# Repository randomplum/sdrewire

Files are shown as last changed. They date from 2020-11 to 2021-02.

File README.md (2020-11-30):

# SDReWire

Modern SD card muxer - allows to mux a SD card between an on-board USB SD card
reader and the device SDReWire is plugged into. This is useful for developing
and testing (embedded) systems which often require SD cards to boot from. It
allows to access the SD card on the target system as well as from the host
system connected via USB without having to touch the SD card.
 
Inspiried by the SDWire.

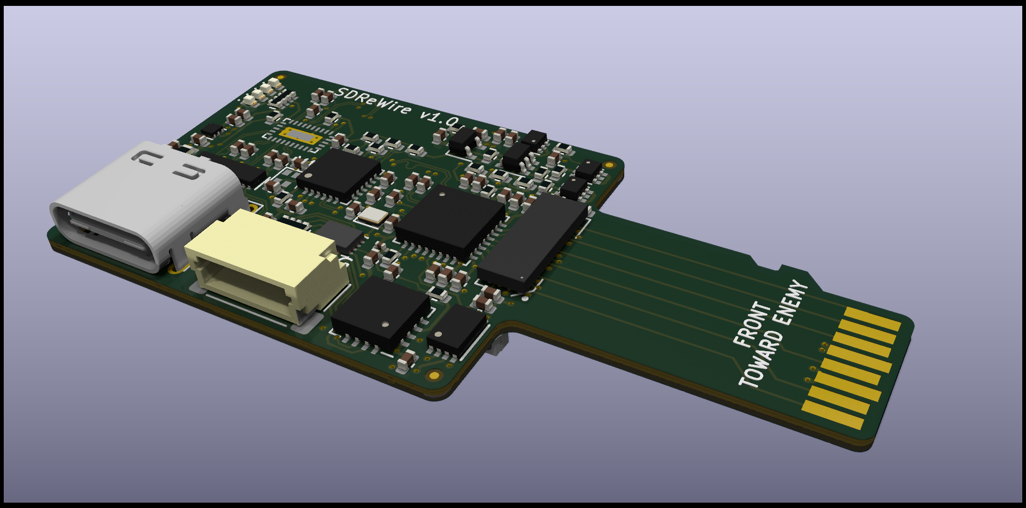
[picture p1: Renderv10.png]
Render


## Features

- USB-C connector for host system
- High speed signal muxer to mux SD signals
- SDXC/UHS capable design
- USB 3.1 Gen1 card reader (90MB/s+)
- FTDI for SD muxing and auxiliary port
- Auxiliary port featuring:
  - UART
  - 2 GPIO (1x output only)
  - 1.2V/1.8V/3.3V capable

Currenlty SDReWire is still in testing and development phase.

### Details

In case you wonder what exact components are used, here is the gist:

- USB 3.1 Gen1 card reader Genesys Logic GL3224
- TS3DDR4000ZBAR mux IC used for SD signals
- FTDI FT230XQ provides GPIO for mux as well as auxiliary UART and GPIO
- USB2422 USB 2.0 Hub to interface GL3224 and FTDI FT230XQ
  
Designed with KiCad.

## License

Licensed under the CERN-OHL-W (CERN Open Hardware Licence Version 2 - Weakly
Reciprocal, see LICENSE).

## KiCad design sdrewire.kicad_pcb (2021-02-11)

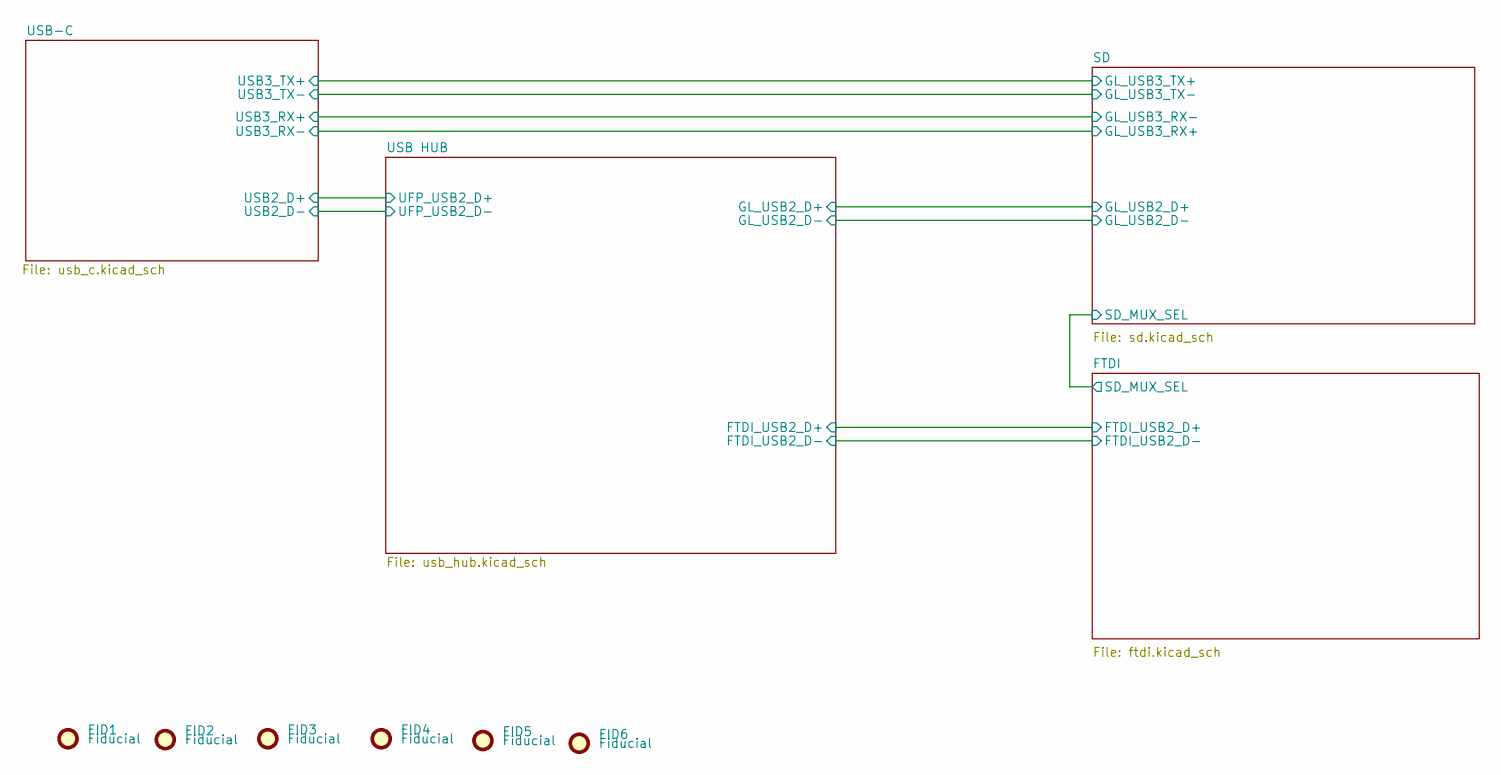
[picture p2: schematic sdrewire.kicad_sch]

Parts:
FID1, FID2, FID3, FID4, FID5, FID6: Fiducial; Fiducial_0.5mm_Mask1mm

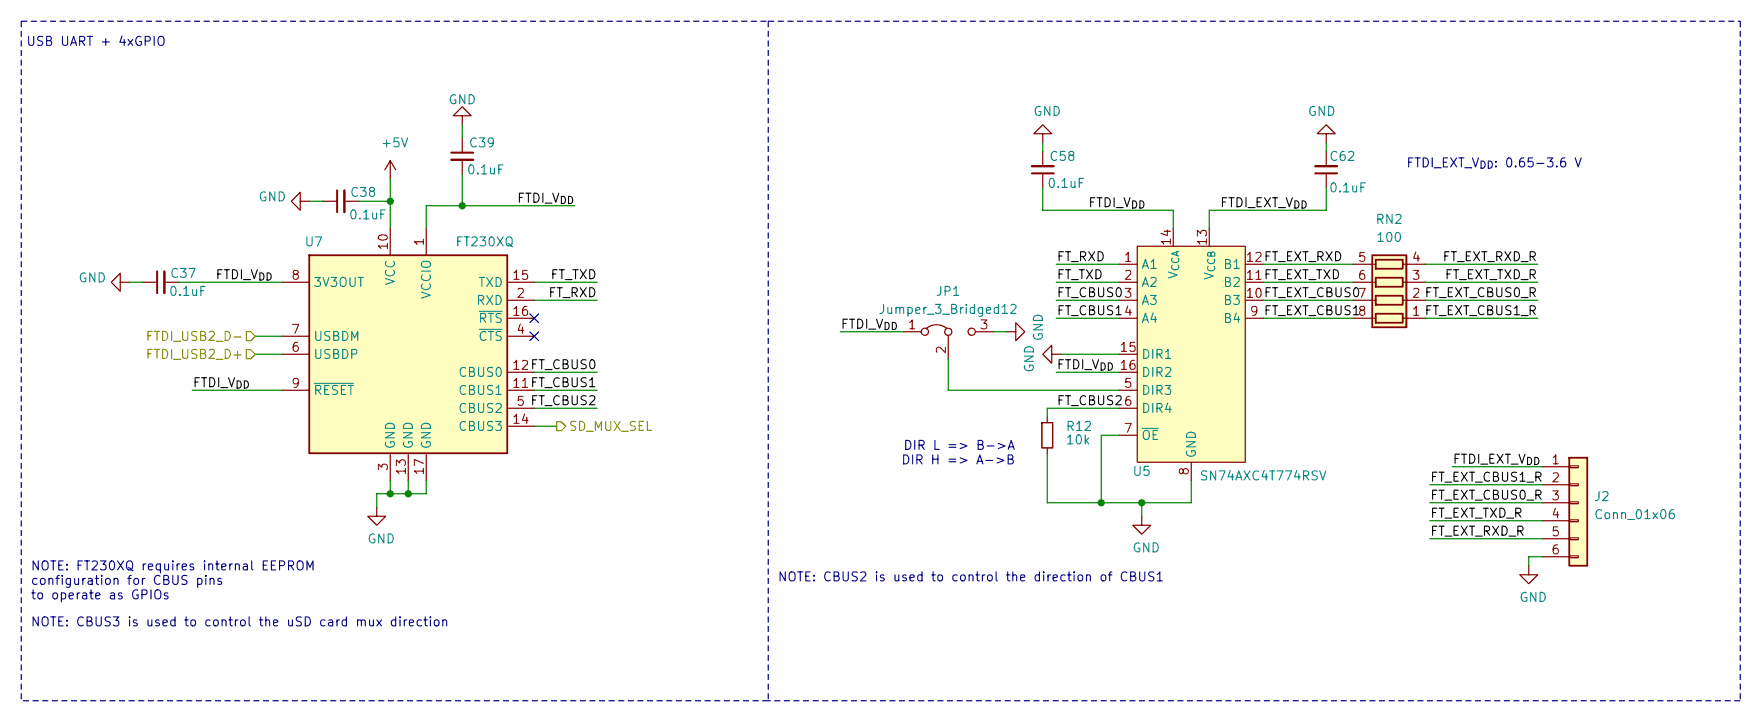
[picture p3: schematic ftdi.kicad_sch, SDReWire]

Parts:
C37, C38, C39, C58, C62: 0.1uF; C_0402_1005Metric
J2: Conn_01x06; JST_SH_SM06B-SRSS-TB_1x06-1MP_P1.00mm_Horizontal
JP1: Jumper_3_Bridged12; SolderJumper-3_P1.3mm_Bridged12_RoundedPad1.0x1.5mm_NumberL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
R12: 10k; R_0402_1005Metric
RN2: 100; R_Array_Convex_4x0402
U5: SN74AXC4T774RSV; QFN-16_1.8x2.6_Pitch0.4mm
U7: FT230XQ; QFN-16-1EP_4x4mm_P0.65mm_EP2.1x2.1mm

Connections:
+5V: C38.2, U7.10 (VCC); also elsewhere on the board
/FTDI/FTDI_EXT_V_{DD}: C62.1, J2.1, U5.13 (V_{CCB})
/FTDI/FTDI_USB2_D+: U7.6 (USBDP); also elsewhere on the board
/FTDI/FTDI_USB2_D-: U7.7 (USBDM); also elsewhere on the board
/FTDI/FTDI_V_{DD}: C37.2, C39.2, C58.1, JP1.1 (A), U5.14 (V_{CCA}), U5.16 (DIR2), U7.1 (VCCIO), U7.8 (3V3OUT), U7.9 (~RESET)
/FTDI/FT_CBUS0: U5.3 (A3), U7.12 (CBUS0)
/FTDI/FT_CBUS1: U5.4 (A4), U7.11 (CBUS1)
/FTDI/FT_CBUS2: R12.1, U5.6 (DIR4), U7.5 (CBUS2)
/FTDI/FT_EXT_CBUS0: RN2.7 (R2.2), U5.10 (B3)
/FTDI/FT_EXT_CBUS0_R: J2.3, RN2.2 (R2.1)
/FTDI/FT_EXT_CBUS1: RN2.8 (R1.2), U5.9 (B4)
/FTDI/FT_EXT_CBUS1_R: J2.2, RN2.1 (R1.1)
/FTDI/FT_EXT_RXD: RN2.5 (R4.2), U5.12 (B1)
/FTDI/FT_EXT_RXD_R: J2.5, RN2.4 (R4.1)
/FTDI/FT_EXT_TXD: RN2.6 (R3.2), U5.11 (B2)
/FTDI/FT_EXT_TXD_R: J2.4, RN2.3 (R3.1)
/FTDI/FT_RXD: U5.1 (A1), U7.2 (RXD)
/FTDI/FT_TXD: U5.2 (A2), U7.15 (TXD)
/FTDI/SD_MUX_SEL: U7.14 (CBUS3); also elsewhere on the board
GND: C37.1, C38.1, C39.1, C58.2, C62.2, J2.6, JP1.3 (B), R12.2, U5.7 (~OE), U5.8 (GND), U5.15 (DIR1), U7.3 (GND), U7.13 (GND), U7.17 (GND); also elsewhere on the board
unnamed: JP1.2 (C), U5.5 (DIR3)

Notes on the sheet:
USB UART + 4xGPIO
NOTE: FT230XQ requires internal EEPROM configuration for CBUS pins to operate as GPIOs
NOTE: CBUS3 is used to control the uSD card mux direction
NOTE: CBUS2 is used to control the direction of CBUS1
DIR L => B->A DIR H => A->B
FTDI_EXT_V_{DD}: 0.65-3.6 V

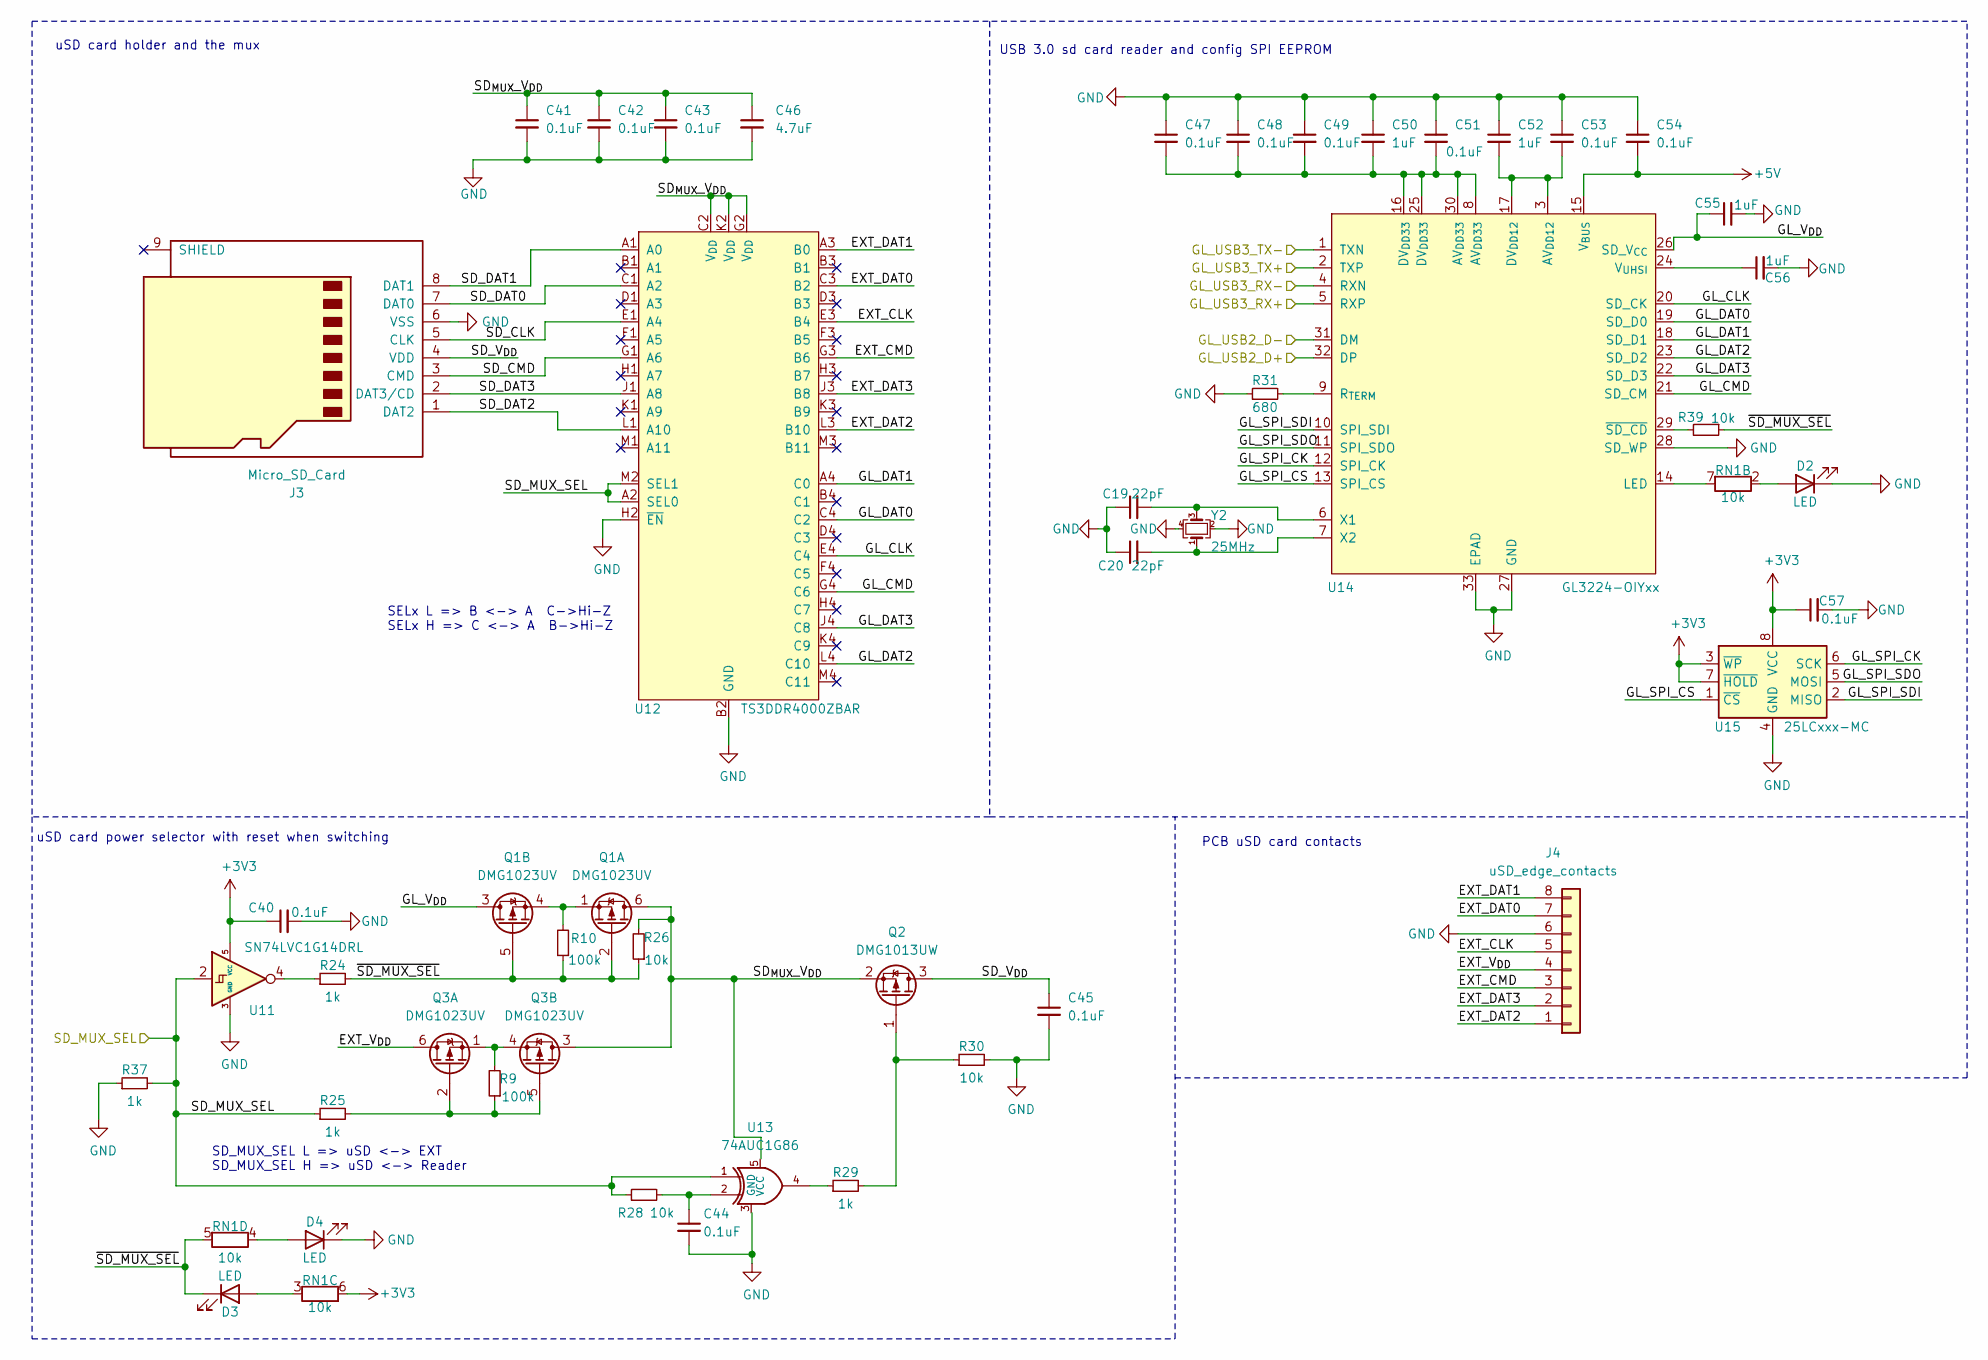
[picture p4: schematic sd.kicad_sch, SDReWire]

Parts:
C19, C20: 22pF; C_0402_1005Metric
C40, C41, C42, C43, C44, C45, C47, C48, C49, C51, C53, C54, C57: 0.1uF; C_0402_1005Metric
C46: 4.7uF; C_0402_1005Metric
C50, C52, C55, C56: 1uF; C_0402_1005Metric
D2, D3, D4: LED; LED_0402_1005Metric
J3: Micro_SD_Card; microSD_HC_Wuerth_693072010801
J4: uSD_edge_contacts; uSD_PCB
Q1, Q3: DMG1023UV; SOT-563
Q2: DMG1013UW; SOT-323_SC-70
R9, R10: 100k; R_0402_1005Metric
R24, R25, R29, R37: 1k; R_0402_1005Metric
R26, R28, R30, R39: 10k; R_0402_1005Metric
R31: 680; R_0402_1005Metric
RN1: 10k; R_Array_Convex_4x0402
U11: SN74LVC1G14DRL; SOT-553
U12: TS3DDR4000ZBAR; Texas_NFBGA-48_3.1x8.1mm_Layout4x12_P0.65mm
U13: 74AUC1G86; SOT-353_SC-70-5
U14: GL3224-OIYxx; QFN-32-1EP_5x5mm_P0.5mm_EP3.1x3.1mm
U15: 25LCxxx-MC; DFN-8-1EP_3x2mm_P0.5mm_EP1.75x1.45mm
Y2: 25MHz; Oscillator_SMD_Abracon_ASCO-4Pin_1.6x1.2mm

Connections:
+3V3: C40.1, C57.1, RN1.6 (R3.2), U11.5 (VCC), U15.3 (~WP), U15.7 (~HOLD), U15.8 (VCC); also elsewhere on the board
+5V: C54.2, U14.15 (V_{BUS}); also elsewhere on the board
/FTDI/SD_MUX_SEL: R25.1, R28.1, R37.2, U11.2, U12.A2 (SEL0), U12.M2 (SEL1), U13.1; also elsewhere on the board
/SD/EXT_CLK: J4.5, U12.E3 (B4)
/SD/EXT_CMD: J4.3, U12.G3 (B6)
/SD/EXT_DAT0: J4.7, U12.C3 (B2)
/SD/EXT_DAT1: J4.8, U12.A3 (B0)
/SD/EXT_DAT2: J4.1, U12.L3 (B10)
/SD/EXT_DAT3: J4.2, U12.J3 (B8)
/SD/EXT_V_{DD}: J4.4, Q3.6 (D)
/SD/GL_CLK: U12.E4 (C4), U14.20 (SD_CK)
/SD/GL_CMD: U12.G4 (C6), U14.21 (SD_CM)
/SD/GL_DAT0: U12.C4 (C2), U14.19 (SD_D0)
/SD/GL_DAT1: U12.A4 (C0), U14.18 (SD_D1)
/SD/GL_DAT2: U12.L4 (C10), U14.23 (SD_D2)
/SD/GL_DAT3: U12.J4 (C8), U14.22 (SD_D3)
/SD/GL_SPI_CK: U14.12 (SPI_CK), U15.6 (SCK)
/SD/GL_SPI_CS: U14.13 (SPI_CS), U15.1 (~CS)
/SD/GL_SPI_SDI: U14.10 (SPI_SDI), U15.2 (MISO)
/SD/GL_SPI_SDO: U14.11 (SPI_SDO), U15.5 (MOSI)
/SD/GL_USB2_D+: U14.32 (DP); also elsewhere on the board
/SD/GL_USB2_D-: U14.31 (DM); also elsewhere on the board
/SD/GL_USB3_RX+: U14.5 (RXP); also elsewhere on the board
/SD/GL_USB3_RX-: U14.4 (RXN); also elsewhere on the board
/SD/GL_USB3_TX+: U14.2 (TXP); also elsewhere on the board
/SD/GL_USB3_TX-: U14.1 (TXN); also elsewhere on the board
/SD/GL_V_{DD}: C55.1, Q1.3 (D), U14.26 (SD_V_{CC})
/SD/SD_CLK: J3.5 (CLK), U12.E1 (A4)
/SD/SD_CMD: J3.3 (CMD), U12.G1 (A6)
/SD/SD_DAT0: J3.7 (DAT0), U12.C1 (A2)
/SD/SD_DAT1: J3.8 (DAT1), U12.A1 (A0)
/SD/SD_DAT2: J3.1 (DAT2), U12.L1 (A10)
/SD/SD_DAT3: J3.2 (DAT3/CD), U12.J1 (A8)
/SD/SD_V_{DD}: C45.1, J3.4 (VDD), Q2.3 (D)
/SD/SD_{MUX}_V_{DD}: C41.1, C42.1, C43.1, C46.1, Q1.6 (D), Q2.2 (S), Q3.3 (D), R26.2, U12.C2 (V_{DD}), U12.G2 (V_{DD}), U12.K2 (V_{DD})
/SD/~SD_MUX_SEL: D3.1 (K), Q1.2 (G), Q1.5 (G), R10.1, R24.2, R26.1, R39.1, RN1.5 (R4.2)
GND: C19.1, C20.1, C40.2, C41.2, C42.2, C43.2, C44.2, C45.2, C46.2, C47.1, C48.1, C49.1, C50.1, C51.1, C52.1, C53.1, C54.1, C55.2, C56.2, C57.2, D2.1 (K), D4.1 (K), J3.6 (VSS), J4.6, R30.2, R31.1, R37.1, U11.3 (GND), U12.B2 (GND), U12.D2 (GND), U12.E2 (GND), U12.F2 (GND), U12.H2 (~EN), U12.J2 (GND), U12.L2 (GND), U14.27 (GND), U14.28 (SD_WP), U14.33 (EPAD), U15.4 (GND), U15.9 (GND), Y2.2, Y2.4; also elsewhere on the board
unnamed: C19.2, U14.6 (X1), Y2.3
unnamed: C20.2, U14.7 (X2), Y2.1
unnamed: C44.1, R28.2, U13.2
unnamed: C47.2, C48.2, C49.2, C50.2, C51.2, U14.8 (AV_{DD33}), U14.16 (DV_{DD33}), U14.25 (DV_{DD33}), U14.30 (AV_{DD33})
unnamed: C52.2, C53.2, U14.3 (AV_{DD12}), U14.17 (DV_{DD12})
unnamed: C56.1, U14.24 (V_{UHSI})
unnamed: D2.2 (A), RN1.2 (R2.1)
unnamed: D3.2 (A), RN1.3 (R3.1)
unnamed: D4.2 (A), RN1.4 (R4.1)
unnamed: Q1.1 (S), Q1.4 (S), R10.2
unnamed: Q2.1 (G), R29.2, R30.1
unnamed: Q3.1 (S), Q3.4 (S), R9.2
unnamed: Q3.2 (G), Q3.5 (G), R9.1, R25.2
unnamed: R24.1, U11.4
unnamed: R29.1, U13.4
unnamed: R31.2, U14.9 (R_{TERM})
unnamed: R39.2, U14.29 (~SD_CD)
unnamed: RN1.7 (R2.2), U14.14 (LED)

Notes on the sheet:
uSD card power selector with reset when switching
SD_MUX_SEL L => uSD <-> EXT SD_MUX_SEL H => uSD <-> Reader
uSD card holder and the mux
SELx L => B <-> A C->Hi-Z SELx H => C <-> A B->Hi-Z
USB 3.0 sd card reader and config SPI EEPROM
PCB uSD card contacts

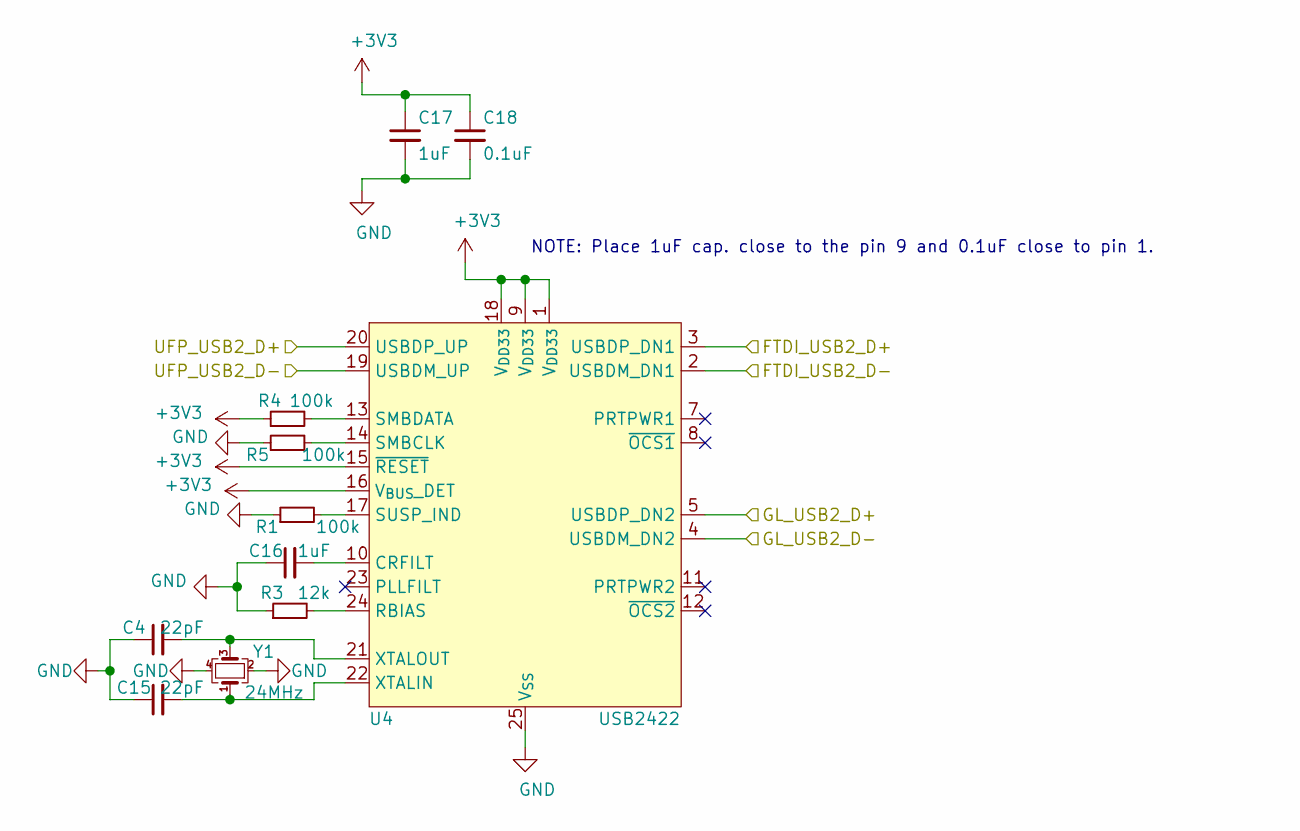
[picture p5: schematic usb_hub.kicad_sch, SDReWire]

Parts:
C4, C15: 22pF; C_0402_1005Metric
C16, C17: 1uF; C_0402_1005Metric
C18: 0.1uF; C_0402_1005Metric
R1, R4, R5: 100k; R_0402_1005Metric
R3: 12k; R_0402_1005Metric
U4: USB2422; QFN-24-1EP_4x4mm_P0.5mm_EP2.6x2.6mm
Y1: 24MHz; Oscillator_SMD_Abracon_ASCO-4Pin_1.6x1.2mm

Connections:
+3V3: C17.1, C18.1, R4.1, U4.1 (V_{DD33}), U4.9 (V_{DD33}), U4.15 (~RESET), U4.16 (V_{BUS}_DET), U4.18 (V_{DD33}); also elsewhere on the board
/FTDI/FTDI_USB2_D+: U4.3 (USBDP_DN1); also elsewhere on the board
/FTDI/FTDI_USB2_D-: U4.2 (USBDM_DN1); also elsewhere on the board
/SD/GL_USB2_D+: U4.5 (USBDP_DN2); also elsewhere on the board
/SD/GL_USB2_D-: U4.4 (USBDM_DN2); also elsewhere on the board
/USB HUB/UFP_USB2_D+: U4.20 (USBDP_UP); also elsewhere on the board
/USB HUB/UFP_USB2_D-: U4.19 (USBDM_UP); also elsewhere on the board
GND: C4.1, C15.1, C16.1, C17.2, C18.2, R1.1, R3.1, R5.1, U4.25 (V_{SS}), Y1.2, Y1.4; also elsewhere on the board
unnamed: C4.2, U4.21 (XTALOUT), Y1.3
unnamed: C15.2, U4.22 (XTALIN), Y1.1
unnamed: C16.2, U4.10 (CRFILT)
unnamed: R3.2, U4.24 (RBIAS)
unnamed: R4.2, U4.13 (SMBDATA)
unnamed: R5.2, U4.14 (SMBCLK)
unnamed: R1.2, U4.17 (SUSP_IND)

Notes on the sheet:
NOTE: Place 1uF cap. close to the pin 9 and 0.1uF close to pin 1.

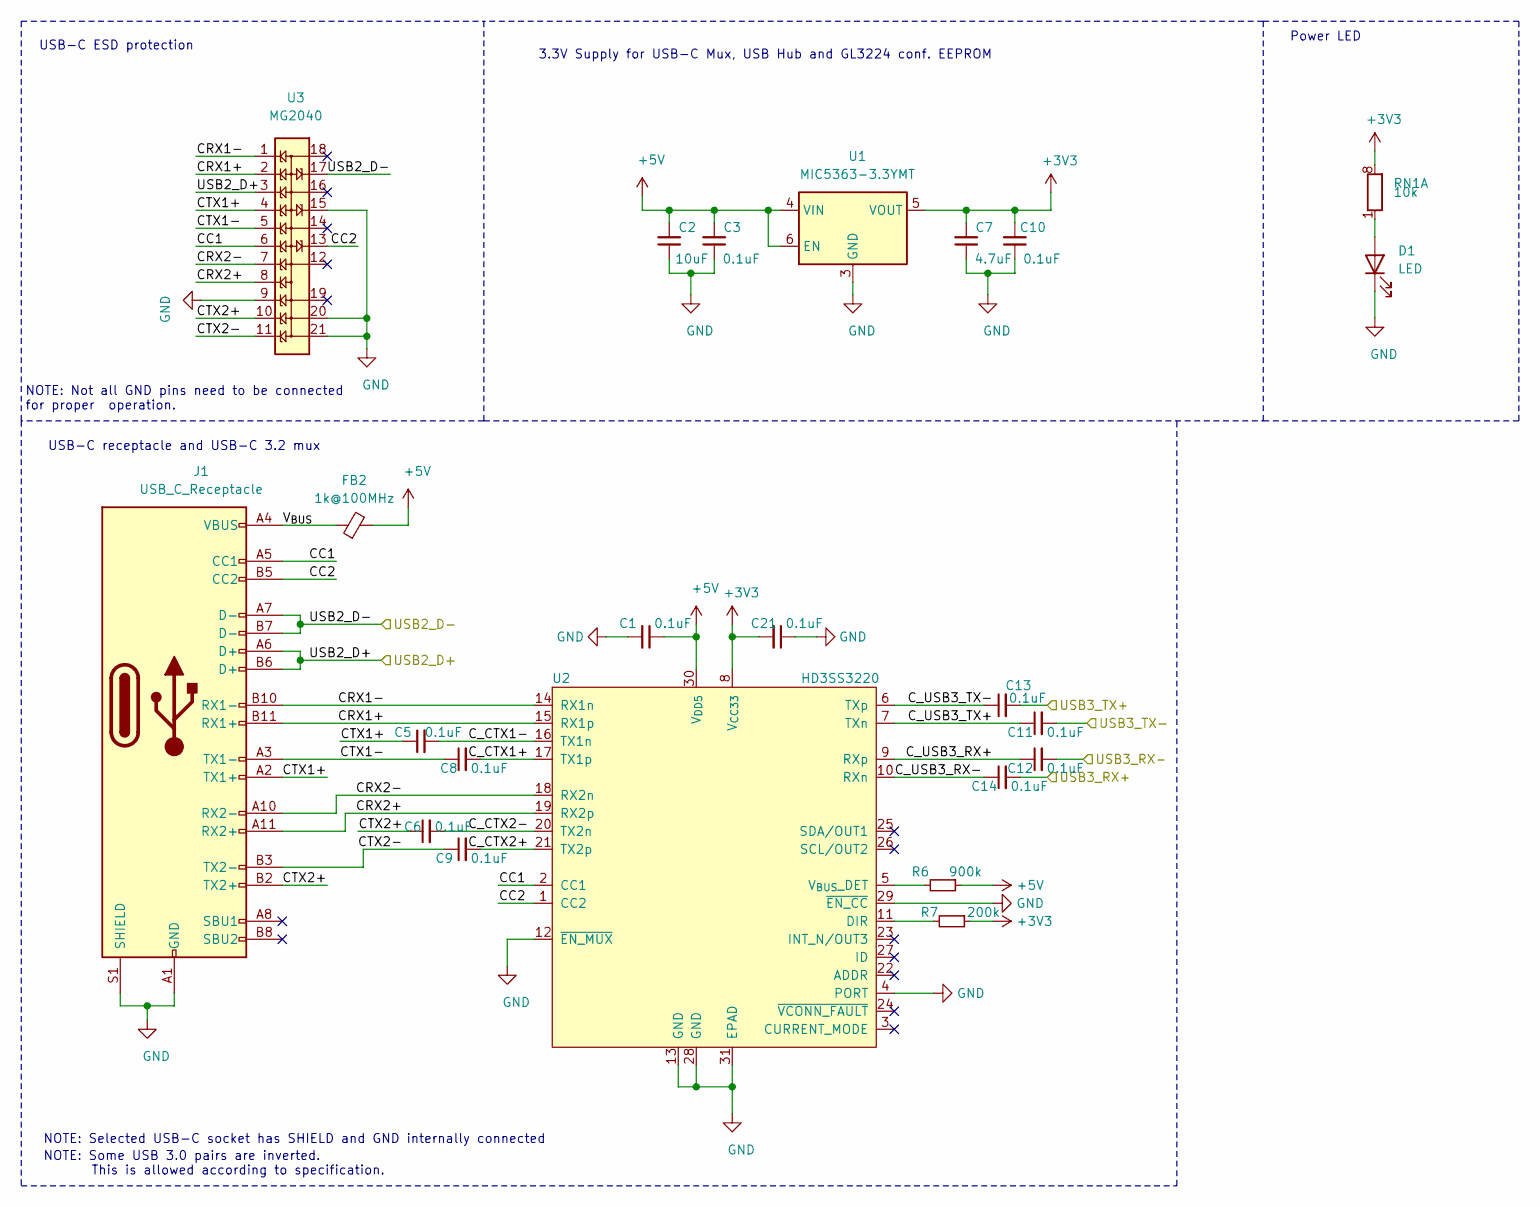
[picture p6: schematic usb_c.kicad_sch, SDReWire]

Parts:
C1, C3, C5, C6, C8, C9, C10, C11, C12, C13, C14, C21: 0.1uF; C_0402_1005Metric
C2: 10uF; C_0402_1005Metric
C7: 4.7uF; C_0402_1005Metric
D1: LED; LED_0402_1005Metric
FB2: 1k@100MHz; R_0603_1608Metric
J1: USB_C_Receptacle; USB_C_Receptacle_Molex_1054500101
R6: 900k; R_0402_1005Metric
R7: 200k; R_0402_1005Metric
RN1: 10k; R_Array_Convex_4x0402
U1: MIC5363-3.3YMT; DFN-6-1EP_1.2x1.2mm_P0.4mm_EP0.3x0.94mm_PullBack
U2: HD3SS3220; WQFP-30-1EP_4.6x2.6mm_P0.4mm_EP3.2x1.2mm
U3: MG2040; UDFN-18-3EP_5.5x1.5mm_P0.5mm_EP0.5x0.5mm

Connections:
+3V3: C7.2, C10.2, C21.2, R7.1, RN1.8 (R1.2), U1.5 (VOUT), U2.8 (V_{CC33}); also elsewhere on the board
+5V: C1.1, C2.2, C3.2, FB2.2, R6.1, U1.4 (VIN), U1.6 (EN), U2.30 (V_{DD5}); also elsewhere on the board
/SD/GL_USB3_RX+: C12.2; also elsewhere on the board
/SD/GL_USB3_RX-: C14.2; also elsewhere on the board
/SD/GL_USB3_TX+: C13.2; also elsewhere on the board
/SD/GL_USB3_TX-: C11.2; also elsewhere on the board
/USB HUB/UFP_USB2_D+: J1.A6 (D+), J1.B6 (D+), U3.3; also elsewhere on the board
/USB HUB/UFP_USB2_D-: J1.A7 (D-), J1.B7 (D-), U3.17; also elsewhere on the board
/USB-C/CC1: J1.A5 (CC1), U2.2 (CC1), U3.6
/USB-C/CC2: J1.B5 (CC2), U2.1 (CC2), U3.13
/USB-C/CRX1+: J1.B11 (RX1+), U2.15 (RX1p), U3.2
/USB-C/CRX1-: J1.B10 (RX1-), U2.14 (RX1n), U3.1
/USB-C/CRX2+: J1.A11 (RX2+), U2.19 (RX2p), U3.8
/USB-C/CRX2-: J1.A10 (RX2-), U2.18 (RX2n), U3.7
/USB-C/CTX1+: C5.1, J1.A2 (TX1+), U3.4
/USB-C/CTX1-: C8.1, J1.A3 (TX1-), U3.5
/USB-C/CTX2+: C6.1, J1.B2 (TX2+), U3.10
/USB-C/CTX2-: C9.1, J1.B3 (TX2-), U3.11
/USB-C/C_CTX1+: C8.2, U2.17 (TX1p)
/USB-C/C_CTX1-: C5.2, U2.16 (TX1n)
/USB-C/C_CTX2+: C9.2, U2.21 (TX2p)
/USB-C/C_CTX2-: C6.2, U2.20 (TX2n)
/USB-C/C_USB3_RX+: C12.1, U2.9 (RXp)
/USB-C/C_USB3_RX-: C14.1, U2.10 (RXn)
/USB-C/C_USB3_TX+: C11.1, U2.7 (TXn)
/USB-C/C_USB3_TX-: C13.1, U2.6 (TXp)
/USB-C/V_{BUS}: FB2.1, J1.A4 (VBUS), J1.A9 (VBUS), J1.B4 (VBUS), J1.B9 (VBUS)
GND: C1.2, C2.1, C3.1, C7.1, C10.1, C21.1, D1.1 (K), J1.A1 (GND), J1.A12 (GND), J1.B1 (GND), J1.B12 (GND), J1.S1 (SHIELD), U1.3 (GND), U1.7 (ePad), U2.4 (PORT), U2.12 (~EN_MUX), U2.13 (GND), U2.28 (GND), U2.29 (~EN_CC), U2.31 (EPAD), U3.9, U3.15, U3.20, U3.21; also elsewhere on the board
unnamed: D1.2 (A), RN1.1 (R1.1)
unnamed: R6.2, U2.5 (V_{BUS}_DET)
unnamed: R7.2, U2.11 (DIR)

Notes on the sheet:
NOTE: Not all GND pins need to be connected for proper operation.
USB-C ESD protection
NOTE: Selected USB-C socket has SHIELD and GND internally connected
NOTE: Some USB 3.0 pairs are inverted. This is allowed according to specification.
USB-C receptacle and USB-C 3.2 mux
3.3V Supply for USB-C Mux, USB Hub and GL3224 conf. EEPROM
Power LED

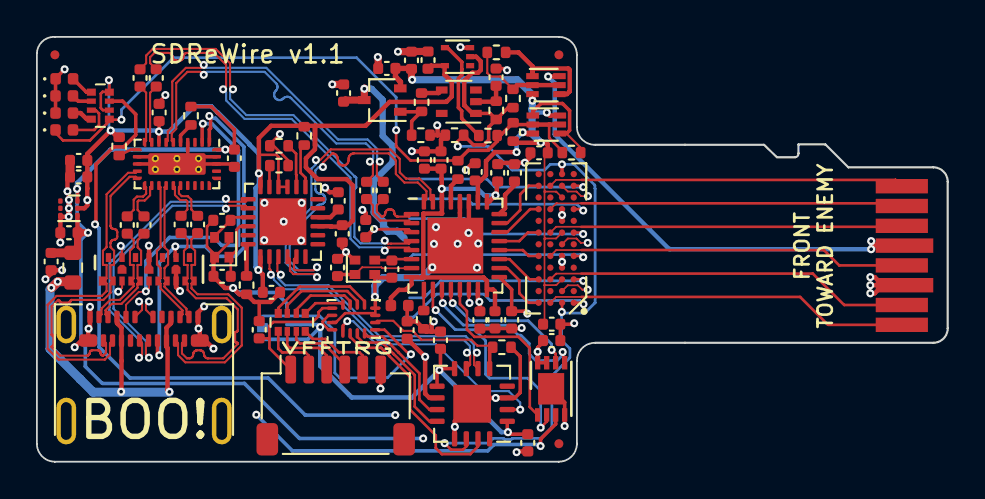
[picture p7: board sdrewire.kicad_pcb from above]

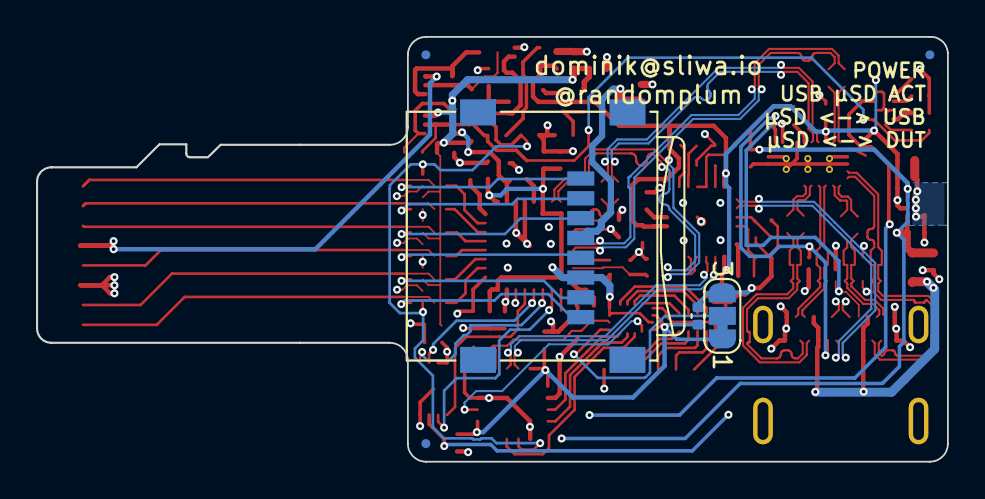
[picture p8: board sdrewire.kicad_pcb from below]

Board: 4 copper layers, 50.6 x 23.6 mm, 96 parts (6 on the bottom side), 104 nets.

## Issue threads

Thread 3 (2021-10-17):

How to purchase / get one produced?

colemickens, 2021-10-17:
Hi.

How can I purchase one, or get one produced?

Thanks! And thanks for the project(s)!

randomplum, 2021-10-20:
Fully assembled and including the JST SH to 0.1" cable

colemickens, 2022-02-08:
Hi @randomplum, I hope things are going well for you. I realize that the supply shortage issues are still very much in effect, but I am again finding myself regularly wishing that I had one of these. I'm not sure what the BOM+assembly (+cost of your time) comes out to, but I suspect I'd be willing to pay a pretty premium on that in order to acquire a few of these.

randomplum, 2022-02-14:
Hi @colemickens ,

I'm well, hope same for you. Great timing. I just got the v1.1 pcb panels and will most likely produce a first batch of 20pcs by the end of week.

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

Will keep you posted, the price will most likely be ~65$ plus shipping from Switzerland.

jwessel, 2022-05-16:
I am interested in purchasing one of the fully assembled boards as well. I took a look at http://tindie.com/ but didn't find any available.

Thanks for all your work on this project.

bzvbzv, 2023-04-01:
Hello, Thank you for the great project.
What's the status of the project now? Are there any finished board which is tested ok?

gamelaster, 2023-04-02:
I purchased SDWireC from: https://www.tindie.com/products/badgerdnl/sdwire-usb-c-sd-card-reader-sd-mux/  . Also it is possible to buy SDwire from 3mbed.com

colemickens, 2023-04-02:
That's not really the same thing, though.

randomplum, 2023-04-02:
Hi All,

Just a quick update, between problems in sourcing chips and getting fake/broken ones. I've put this project on hold last year. Unfortunately it looks like the GL3224 (the sd card reader chip) availability did not get any better. I'm currently evaluating CH565W as a replacement, but It's not a high priority project for me at the moment.

gamelaster, 2023-04-02:
@colemickens of course, but just wanted to show available alternatives, having sdrewire would be best, but since it is still not available, both SDWire and SDWireC are quite good.

@randomplum good luck with the evaluating CH565W, looking forward :)

InfraredRidingHood, 2025-09-03:
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

Hello,

I'm wondering if you will be posting the V1.1 files and if it's worth my time trying to assemble some of these boards?

Thanks, Stephen.

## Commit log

2020-11-23 SDReWire: v1 schematics
    [ftdi.kicad_sch, sd.kicad_sch, sdrewire.kicad_sch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]
2020-11-23 sd.kicad_sch: fix power select PMOSes
    Back-to-back configuration should use transitors from the same package.
    [sd.kicad_sch]
2020-11-23 SDReWire: Footprint assigment
    [ftdi.kicad_sch, sd.kicad_sch, sdrewire.kicad_sch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]
2020-11-23 SDReWire: rename FTDI_GPIO to SD_MUX_SEL and fix assigment
    Resistor array had a wrong footprint
    [ftdi.kicad_sch, sd.kicad_sch, sdrewire.kicad_sch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]
2020-11-23 SDReWire: fix assigments
    modify few components footprint assigments
    [ftdi.kicad_sch, sd.kicad_sch, sdrewire.kicad_sch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]
2020-11-23 sdrewire.kicad_pcb: initial PCB file
    [sdrewire.kicad_pcb]
2020-11-23 SDReWire: add configurable link for gpio dir
    [ftdi.kicad_sch, sd.kicad_sch, sdrewire.kicad_pcb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]
2020-11-23 sd.kicad_sch: improve SD_MUX_SEL net readability
    [ftdi.kicad_sch, sd.kicad_sch, sdrewire.kicad_pcb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]
2020-11-23 SDReWire: fix MIC5363 symbol
    [sd.kicad_sch, sdrewire.kicad_pcb, sdrewire.kicad_sch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]
2020-11-23 usb_c.kicad_sch: swap usb 3 pairs at MG2040
    [usb_c.kicad_sch]
2020-11-24 Fix direction of hierarchical label SD_MUX_SEL
    [ftdi.kicad_sch, sdrewire.kicad_sch]
2020-11-24 Update README.md
    Added 1.2V ftdi IO voltage option and few fixups.
2020-11-29 sdrewire: pcb v1
    Some itra-pair inversions for easier routing.
    Fixed crystal pinouts
    sd power p-fet changed for smaller package
    [ftdi.kicad_sch, sd.kicad_sch, sdrewire.kicad_pcb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]
2020-11-30 SDReWire: v1.0 production data
    [sdrewire-B_Cu.gbr, sdrewire-B_Mask.gbr, sdrewire-B_Silkscreen.gbr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]
2020-12-02 SDReWire: fix back-to-back transistors circuit
    [ftdi.kicad_sch, sd.kicad_sch, sdrewire.kicad_pcb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]
2021-02-10 Changes:
    -fix led order
    -fix transistor routing
    -modify usb hub strapping and fix crystal footprint
    -remove copper under sd pads
    -routing cleanup
    -change revision to 1.1
    [ftdi.kicad_sch, sd.kicad_sch, sdrewire.kicad_pcb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]
2021-02-11 PCB: traces cleanup
    [sdrewire.kicad_pcb]
